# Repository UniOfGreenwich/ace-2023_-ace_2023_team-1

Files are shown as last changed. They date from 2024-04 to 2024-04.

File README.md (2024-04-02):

Review Assignment Due Date (https://classroom.github.com/a/vcAhwuzK)
# Design & Development of a Modular High-Performance Computer (HPC)
## ELEE1119 Advanced Computer Engineering | Academic Year 2023/24
<p align="center">
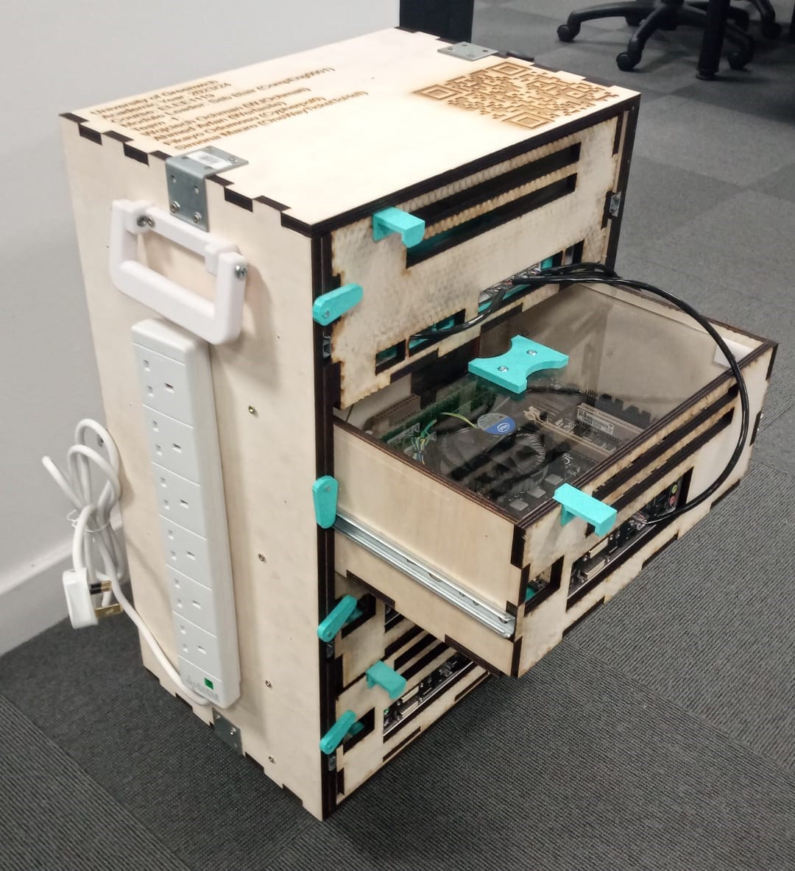
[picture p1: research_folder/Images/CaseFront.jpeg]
Front Case
  
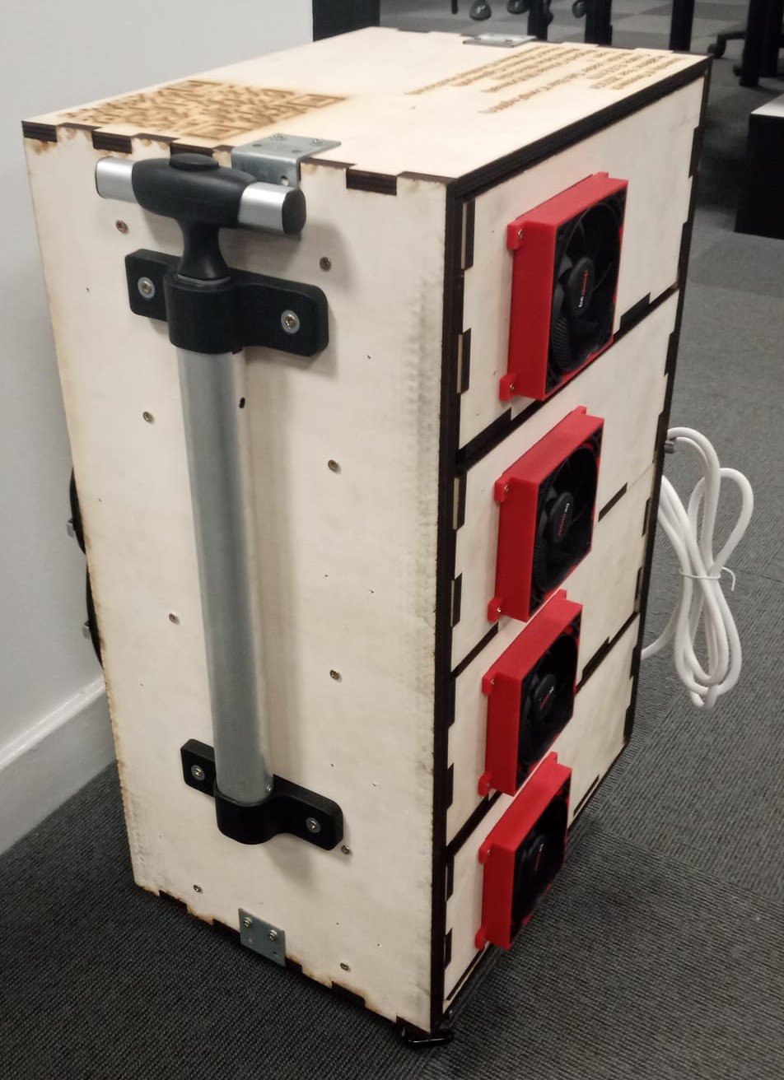
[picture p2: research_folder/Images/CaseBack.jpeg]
Back Case
  
</p>

## Table of Contents
- [Design \& Development of a Modular High-Performance Computer (HPC)](#design--development-of-a-modular-high-performance-computer-hpc)
  - [ELEE1119 Advanced Computer Engineering | Academic Year 2023/24](#elee1119-advanced-computer-engineering--academic-year-202324)
  - [Table of Contents](#table-of-contents)
  - [Video](#video)
  - [Introduction](#introduction)
  - [Setup](#setup)
  - [Design and Manufacturing](#design-and-manufacturing)
    - [Cooling overview](#cooling-overview)
  - [Software Implementation](#software-implementation)
    - [PXE Boot](#pxe-boot)
    - [OpenSSH](#openssh)
    - [Slurm](#slurm)
    - [Testing with R](#testing-with-r)
  - [Recommendations](#recommendations)
  - [Contributors](#contributors)
  - [License](#license)

## Video
<p align="center">
  <a href="https://www.youtube.com/watch?v=2bO4xLcN6Lk" title="Watch the Video">
    Video Report
  </a>
</p>

## Introduction
Welcome to the README file for the Advanced Computer Engineering module at the University of Greenwich, Academic Year 2023/24. This module is lead by Sebastian Blair. This project has been developed by `Team -1`. For full list of contributors consider the [contributors](#contributors) section.

This document provides an overview of the Design and Implementation of the High Performance Computing (HPC) System, including a brief explanation of the steps taken to develop the final products: a prototype, video and documentation demonstrating the collaborative effort and technical approach.

The HPC involves using multiple and interconnected computers in a cluster to perform complex computations. These clusters are nodes managed by schedulers to optimise resource usage. LinuxⓇ is the leading operating system for HPC. It is important to note that although a significant milestone has been reached with the creation of this prototype, there is room for further development and improvements.

## Setup
To carry out this project, the foundational components required are a Raspberry Pi (Model 4B), 3 Motherboards (ASUS CSB), and a 4/5 port switch. The Raspberry Pi acts as the head node, and the motherboards acting as compute nodes.

## Design and Manufacturing
To manufacture a copy of the HPC, an FDM (Fused Deposition Modeling) 3D Printer is necessary with a minimum hotbed size of 300 by 300mm, and a laser cutter with the minimum size of 300 by 600mm. 

PLA (Polylactic Acid) has been used as the filament of choice in this prototype, however ABS or PETG are just as appropriate. The laser cutting has been done using 9mm thick plywood, it is recommended to keep the thickness at 9mm. However, alternative materials such as acrlyic may be used instead of plywood. All CAD, STL, 3VS, and DXF design files can be located in the `hpc_case_design` folder of this repository. [Click Here](/hpc_case_design/design_readme.md) to learn more about the design and manufacturing of this project. 

### Cooling overview
Cooling for this HPC was done through a combination of various cooling methods like row cooling, forced convection and raised floor cooling. Knowing the wattage of the HPC allowed for calculation of the cooling requirements using BTU/br. With the intake of cool air, the exhaust space was calculated.</br> View the link below for more info:

- [Click Here](/hpc_case_design/cooling)

## Software Implementation
The HPC cluster here has been setup with two partitions, mycluster and mycluster2 with each having 2 nodes. The nodes are name node01, node02, node03 and node04. node01(headnode) and node04 are part of partition mycluster whereas node02 and node03 are part of partition mycluster2.

### PXE Boot
PXE (Pre-Boot Execution Environment) is a network protocol that allows a computer to boot and load its OS using resources from a server rather than local storage (USB stick, SSD, Hard Dive, etc.). This is done by leveraging the capabilities of DHCP, TFTP and NFS.
The three main packages used as DHCPD, TFTPD and NFS-Server.
DHCPD is used to create a network. TFTPD is used to create a TFTP Server and NFS is to share the OS image and kernel files. 

[Click here](/research_folder/Software/Implementation/PXE.md) to perform these prerequisite steps and PXE boot as a whole.

1. NETWORK SETUP - DHCP
   
   Firstly, all computers in the HPC setup must be able to communicate with each other. The Compute nodes (ASUS motherboards) are all connected to the head node (Raspberry pi) via LAN and are in network. Here, the DHCP (Dynamic Host Configuration Protocol) is used to allow the devices in the network (the other compute nodes) to be dynamically assigned an IP address. This simplifies the process of configuring IP addresses as it is not necessary to perform static routing and addressing on each device of the HPC. Additionally, DHCP assigns the subnet mask, default gateway, domain name server address and other configurations.
   
   To setup DHCP and get more in depth info, [click here](/research_folder/Software/Implementation/PXE.md#dhcp-server) and go to DHCP setup. 
   
<p align="center">
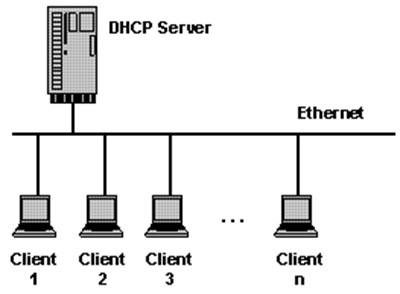
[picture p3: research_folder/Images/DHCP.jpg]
  
</p>

2. SETTING UP TFTP SERVER_
   
   TFTP (Trivial File Transfer Protocol) is a simple, lightweight protocol used to transfer files between devices on a network. It is used to specify the directory which the TFTP server needs to  server to the client. In this case, it is used to serve all the related files required for booting and show the PXE Boot menu, where users can select the operating system to install. Since all related files are stored in the tftpboot directory, this is shared using TFTP.

   To setup TFTP and get more in depth info, [click here](/research_folder/Software/Implementation/PXE.md#configure-tftp-server) and go to TFTP setup.

3. NFS
   
   After selecting the operating system, it is important for users to be able to load the images, kernel files and more. These files need to be accessible over the network. Therefore, NFS (Network File System) is used. This can be done by adding the directory which contains these files as a shared directory across the network. 

   An ISO image of an Ubuntu distribution is firstly installed and mounted. Here, a live installer of Ubuntu 20.04 is installed. It is then copied to a certain directory (ubuntu). This directory now contains all the iso files necessary to install the OS on a machine. This directory needs to be exported over the network and available to compute nodes. Hence it must be configured in the NFS exports file.

   Finally, the PXE Boot menu needs to be configured. The initrd (Initial RAM disk)and vmlinuz (kernel image) files are required to be fetched once user selects operating system. This must be specified in the Boot menu file.

   To setup NFS and get more in depth info, [click here](/research_folder/Software/Implementation/PXE.md#nfs) and go to NFS section. 

Given below is an overview of the entire process
<p align="center">
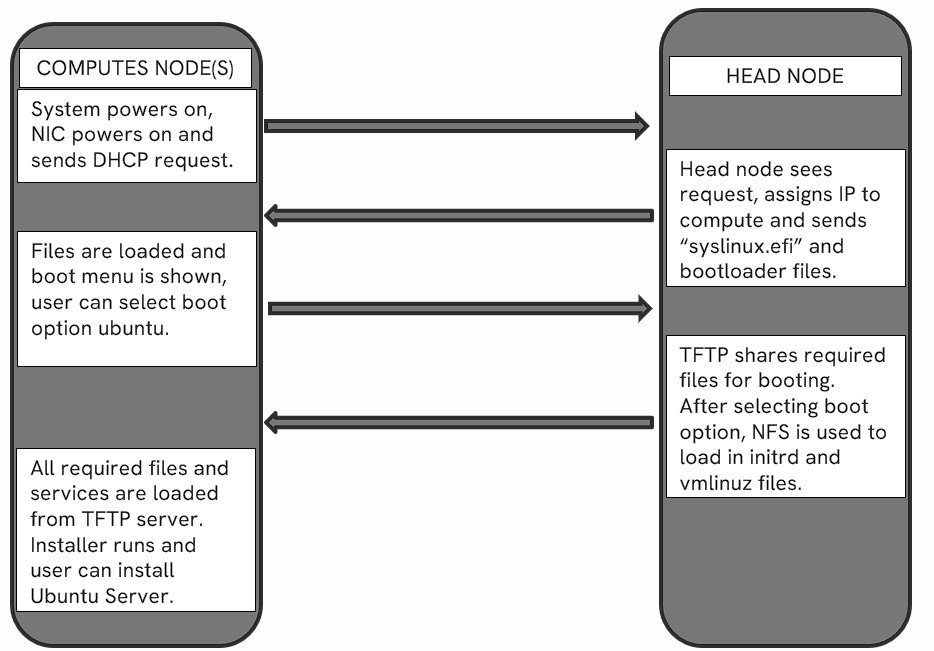
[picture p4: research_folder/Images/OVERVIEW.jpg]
Overview
  
</p>

### OpenSSH
A prerequisite for slurm, to allow secure file transfer and communication between nodes. Allows remote access to compute nodes.</br> For instructions on setting up OpenSSH [Click Here](/research_folder/Software/Implementation/OpenSSH.md#openssh-setup)

### Slurm
Slurm is a highly scalable and flexible workload manager used primarily in HPC environments. Slurm provides mechanisms for inter-task communication and coordination, allowing tasks to share data or synchronize their operations as needed.</br>
SLURM needs to be able to perform its jobs on any node of the cluster. This makes it so that each node should be able to access the same files. Therefore, a shared storage would have to be created. In this project, a 16GB USB drive connected to the head node is exported as a Network File System.

[Click here](/research_folder/Software/Implementation/Slurm.md) to do setup USB as shared storage and setup SLURM between a head node and a compute node. In our setup slurm has been setup for the 4 nodes. Slurmd runs on all nodes whereas node01 runs slurmctld.

### Testing with R

Finally, to test the SLURM setup, an R script is created which generates 10000 random datasets, these datasets are then used to create a density plot jpg. Then the script is run 50 times parallelly on a single partition.  This has been tested and run on the partition mycluster.
Therefore, 50 plots are generated at once, as shown below.

Here are some of the plots:

<p align="center">
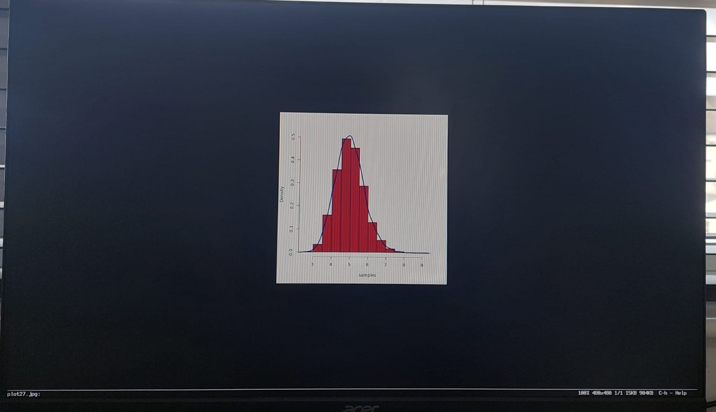
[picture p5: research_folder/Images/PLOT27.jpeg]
Plot 27
  
</p>
<p align="center">
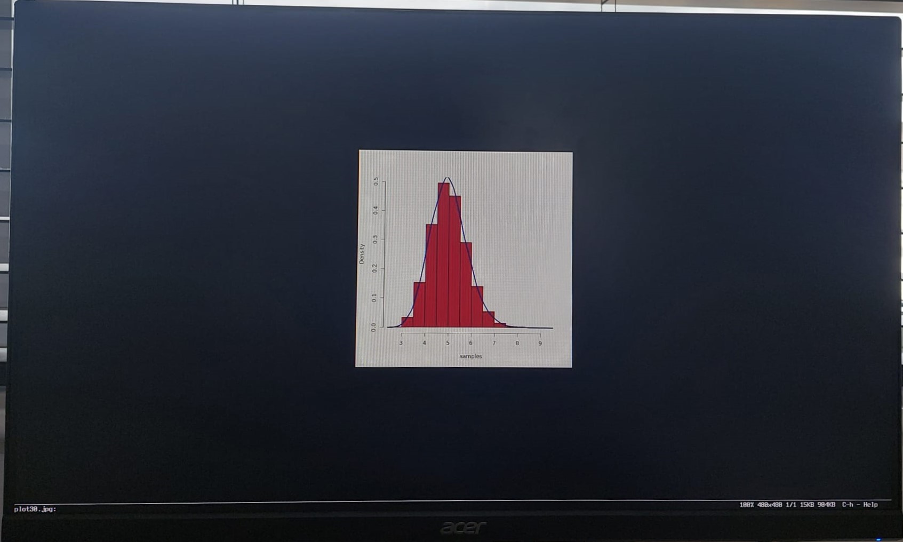
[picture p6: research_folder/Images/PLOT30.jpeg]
Plot 30
  
</p>
<p align="center">
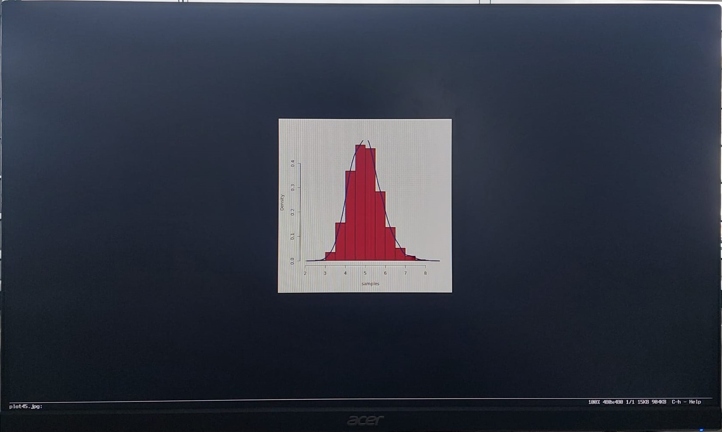
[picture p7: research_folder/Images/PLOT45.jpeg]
Plot 45
  
</p>

[Click here](/research_folder/Software/Implementation/TestRPRogram.md) to view detailed documentation and code.
As a result, SLURM was used to run a job i.e., generating plot from 10000 samples 50 times in parallel. This mimics data processing of large datasets which is a major use case of HPC clusters. 

## Recommendations
Some of the project's next steps include incorporating technologies to improve its capabilities and test its abilities. Integrating SingularityCE can simplify the deployment of complex applications in HPC and scientific computing environments, leveraging containerisation for portability and reproducibility. John the Ripper could enhance security by identifying vulnerabilities in different operating systems. Prometheus and Jaeger will facilitate the monitoring and tracking framework, offering insights into system performance and operational dynamics. Furthermore, these integrations will be relatively easy by taking advantage of Slurm's compatibility with Docker.
Users are encouraged to consult the official documentation linked below for installation guidance on these technologies.

- [SingularityCE Documentation](https://docs.sylabs.io/guides/latest/user-guide/)
- [John the Ripper Documentation](https://github.com/openwall/john/tree/bleeding-jumbo)
- [Prometheus Documentation](https://prometheus.io/docs/prometheus/latest/installation/)
- [Jaeger Documentation](https://www.jaegertracing.io/docs/1.55/getting-started/)

## Contributors
- [@Wertasile](https://github.com/Wertasile)
- [@Cypherpol0](https://github.com/Cypherpol0)
- [@OneWayTicketToHell](https://github.com/OneWayTicketToHell)
- [@WJOchman](https://github.com/WJOchman)
- [@CompEng0001](https://github.com/CompEng0001) - Lecturer

## License
<p xmlns:cc="http://creativecommons.org/ns#" >This work is licensed under <a href="http://creativecommons.org/licenses/by-nc-sa/4.0/?ref=chooser-v1" target="_blank" rel="license noopener noreferrer" style="display:inline-block;">CC BY-NC-SA 4.0</a></p>

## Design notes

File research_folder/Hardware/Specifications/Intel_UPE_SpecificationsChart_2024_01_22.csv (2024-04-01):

UPE | Compare Intel® Products
01/22/2024 12:21:36 PM
 | Intel® Core™ i5-4590 Processor (6M Cache- up to 3.70 GHz)
Essentials
Product Collection | 4th Generation Intel® Core™ i5 Processors
Code Name | Products formerly Haswell
Vertical Segment | Desktop
Processor Number | i5-4590
Lithography | 22 nm
Recommended Customer Price | $202.00
CPU Specifications
Total Cores | 4
Total Threads | 4
Max Turbo Frequency | 3.70 GHz
Intel® Turbo Boost Technology 2.0 Frequency‡ | 3.70 GHz
Processor Base Frequency | 3.30 GHz
Cache | 6 MB Intel® Smart Cache
Bus Speed | 5 GT/s
TDP | 84 W
Supplemental Information
Marketing Status | Discontinued
Launch Date | Q2'14
Expected Discontinuance | 07/14/2017
Servicing Status | End of Servicing Lifetime
End of Servicing Updates Date | Wednesday | June 30 | 2021
Embedded Options Available | No
Datasheet | View now
Memory Specifications
Max Memory Size (dependent on memory type) | 32 GB
Memory Types | DDR3-1333/1600 | DDR3L-1333/1600 @ 1.5V
Max # of Memory Channels | 2
Max Memory Bandwidth | 25.6 GB/s
ECC Memory Supported ‡ | No
GPU Specifications
GPU Name‡ | Intel® HD Graphics 4600
Graphics Base Frequency | 350 MHz
Graphics Max Dynamic Frequency | 1.15 GHz
Graphics Video Max Memory | 2 GB
Graphics Output | eDP/DP/HDMI/VGA
Max Resolution (HDMI)‡ | 4096x2304@24Hz
Max Resolution (DP)‡ | 3840x2160@60Hz
Max Resolution (eDP - Integrated Flat Panel)‡ | 3840x2160@60Hz
Max Resolution (VGA)‡ | 1920x1200@60Hz
DirectX* Support | 11.2/12
OpenGL* Support | 4.3
Intel® Quick Sync Video | Yes
Intel® InTru™ 3D Technology | Yes
Intel® Flexible Display Interface (Intel® FDI) | Yes
Intel® Clear Video HD Technology | Yes
# of Displays Supported ‡ | 3
Device ID | 0x412
Expansion Options
Scalability | 1S Only
PCI Express Revision | Up to 3.0
PCI Express Configurations ‡ | Up to 1x16 | 2x8 | 1x8+2x4
Max # of PCI Express Lanes | 16
Package Specifications
Sockets Supported | FCLGA1150
Max CPU Configuration | 1
Thermal Solution Specification | PCG 2013D
TCASE | 72.72°C
Package Size | 37.5mm x 37.5mm
Advanced Technologies
Intel® Turbo Boost Technology ‡ | 2
Intel® Hyper-Threading Technology ‡ | No
Intel® Transactional Synchronization Extensions | No
Intel® 64 ‡ | Yes
Instruction Set | 64-bit
Instruction Set Extensions | Intel® SSE4.1 | Intel® SSE4.2 | Intel® AVX2
Intel® My WiFi Technology | Yes
Idle States | Yes
Enhanced Intel SpeedStep® Technology | Yes
Thermal Monitoring Technologies | Yes
Intel® Identity Protection Technology ‡ | Yes
Security & Reliability
Intel vPro® Eligibility ‡ | Intel vPro® Platform
Intel® AES New Instructions | Yes
Secure Key | Yes
Intel® OS Guard | Yes
Intel® Trusted Execution Technology ‡ | Yes
Execute Disable Bit ‡ | Yes
Anti-Theft Technology | Yes
Intel® Stable IT Platform Program (SIPP) | Yes
Intel® Virtualization Technology (VT-x) ‡ | Yes
Intel® Virtualization Technology for Directed I/O (VT-d) ‡ | Yes
Intel® VT-x with Extended Page Tables (EPT) ‡ | Yes

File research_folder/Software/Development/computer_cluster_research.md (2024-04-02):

# COMPUTER CLUSTERS

_computer clusters_ are designed to maximise the advantages of parallel computing

In parallel computing tasks are broken down into independent and semi independent operations for simultaneous oepration. this allows for vast increases in computing resources that can be applied to a single tasks allowing for faster execution.

For example, calculation of hours worked, taxes, etc. need to calculated for each employee in a company. Each employees calculations are assigned to separate processor to do all of it simulateneously and faster.

Hardware configuration.

## COMPUTING CLUSTERS - NODE LAYOUT
Computing clusters consist of many specialised nodes

1. HEAD NODE - This is the node into which users must logic to access resources of computer.

2. COMPUTE NODE - Contribute to vast majority of systems computing power. Cannot be accessed by users directly. Instead, Computing jobs must be created on the queue managed by head node.

3. INTERACTIVE NODE - Some computing clusters provide small number of interactive nodes which can be logged into directly. Only intended for small tasks/ short jobs. Alternatively, if interactive nodes are not present, interactive jobs can be launched on compute nodes via the queue.

## COMPUTING CLUSTERS - STORAGE LAYOUT

1. HOME DIRECTORY STORAGE - Users are given small amount of storage for config files, source codew, etc and hsould not be used for large data sets that often form input or output for computational projects.

2. PROJECT STORAGE - large input or output datasets must be stored here.
   
## QUEUES

Queue system may manage several different queues for managing differnet hardware configs

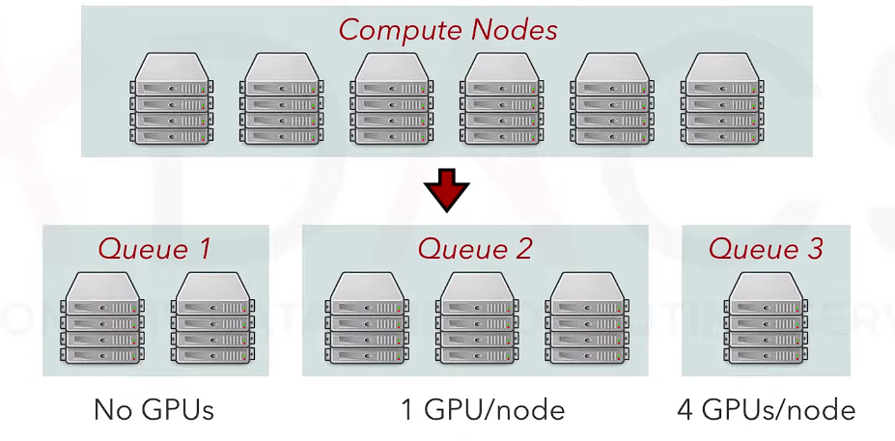
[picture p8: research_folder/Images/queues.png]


It is the responsibility of the user to send the tasks to the correct queue when sent to the queue system.

jobs are submitted to queue system via submission script specify not only the commands to be run by compute nodes but the resources needed as well. the queue system turns the script to a job and specifies job id to identify it.

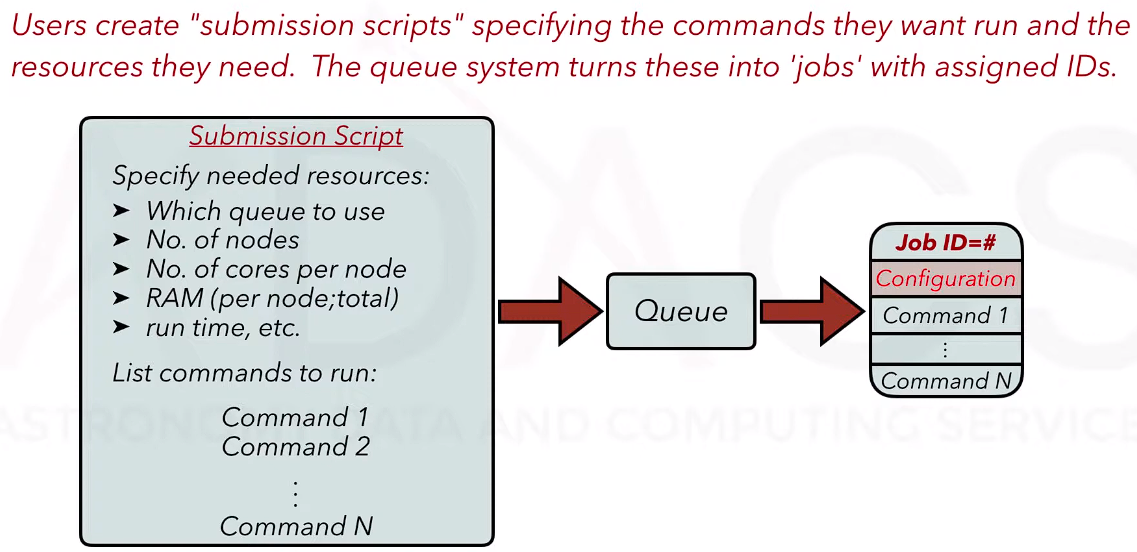
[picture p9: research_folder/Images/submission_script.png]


once jobs are created by queue system they may wait for a bit before starting depending on resources requested and degree to which cluster is being used.

its the job of the queue scheduler to monitor usage patterns of cluster and determine the optimal optimal strategy for starting jobs on computer. It seeks to maximise use of computer and manage equitable access of computer.

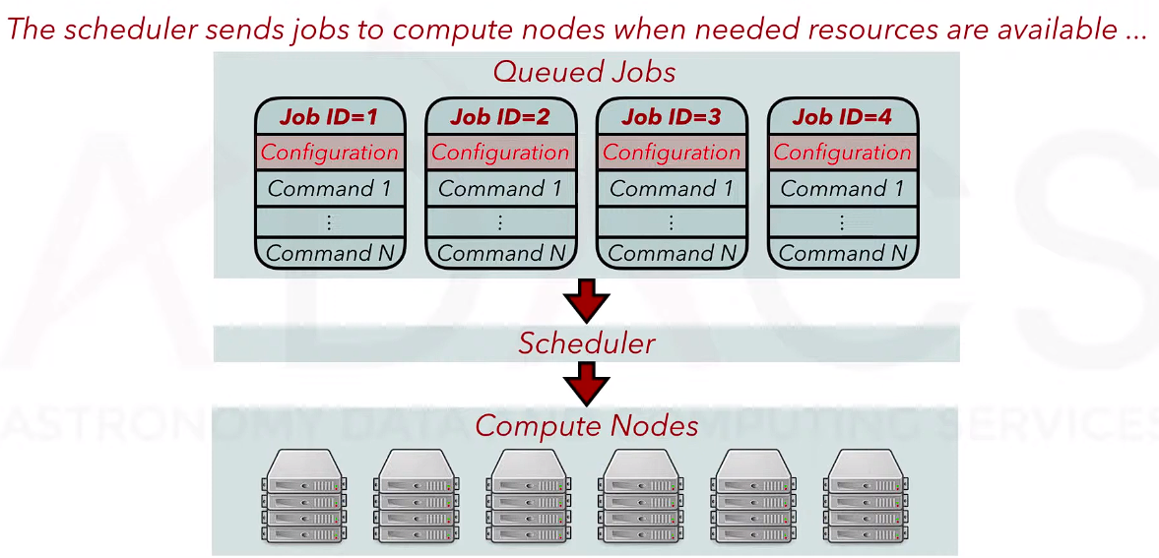
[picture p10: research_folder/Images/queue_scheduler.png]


## SCRIPTS

Operation of computing clusters can be done via a unix command line interface (CLI ) or shell scripts which package sequences of commands allowing for optional arguements. 

Shell script can be created via a text editor like vim.
then system needs to be told the text file is to be considered a executable entity
this is done by setting its permission (read, write and execute) or alternatively,  scripts can be sourced

1. when a shell is executed, a new shell is created or forked and the script is run entirely within the new shell, once complete the forked shell is destroyed and execution return to original shell. As a result, execution occurs in a clean and newly iinitialised environment. 

2. When a script is sourced, it is run within the current shell with its current environment

shell scripts can also receive parameters when executed, and within script these parameters are referenced by a dollar sign followed by a  number $1, $2, $3, ... $n.

## WORKING WITH QUEUES - SUBMISSION SCRIPTS.

submission scripts are shell scripts with additional specialised directives to specify resource requirements, job names, etc. execution privelegesn do not need to be set by chmod. These scripts are sent to the queue with a specialised command which depends on queue system used. Queue management system used here is SLURM - Simple Linux Utility Resource Manager. SLURM submission command is sbastch jobscript.

because there is no way of knowing when or where the job will execute, it is not practical to monitor output of job with the shell we submitted it in. Therefore, standard output produced by job is send to a file. By default, for a jopb with a given name and id the file will be name < name >.o< jobid >

## LOGGING IN COMPUTER CLUSTER

Computing clusters can only be accessed via head nodes, this must be achieved using secure shell (SSH) protocol. external node to compute nodes is not possible.

# SLURM

- preferred way to use a supercomputer is through submitting batch jobs toa  scheduler which governs access to compute nodes

- basic goal of queue system is maximise use of hpc and to do in a fair manner

- ease workload for users and perform complex computation

SLURM is an open source, fault tolerant and highly scalable cluster ,management and job scheduling system for large and small linux clusters.

Developed at Livermore Computing Center, and has grown into a large open source project.

## KEY FUNCTIONS

1. to give users access to rtesources for specified period of time.
   
2. provide a framework for starting, executing and monitoring work on compute nodes.
   
3. to arbitrate contention for resources by managing a queue of pending work.

## ARCHITECTURE

slurm consists of a daemon called slurmd which runs on each compoute node anda  central daemon called alurmctld running on a management node.

info can be queried via several command and can be run in the cluster.

## ENTITIES MANAGED BY SLURM DAEMONS

nodes : computer resources in slurm.

partitions - which group nodes into logical sets, jobs or allocation of resources. can be considered job queues with constraints such as job size limit, job time limit, users permitted to use it, etc.

job steps - set of tasks (maybe parallel) within the job.

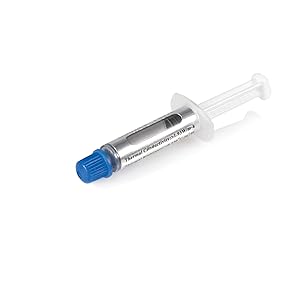
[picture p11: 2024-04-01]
research_folder/Images/thermal_paste_image.jpg

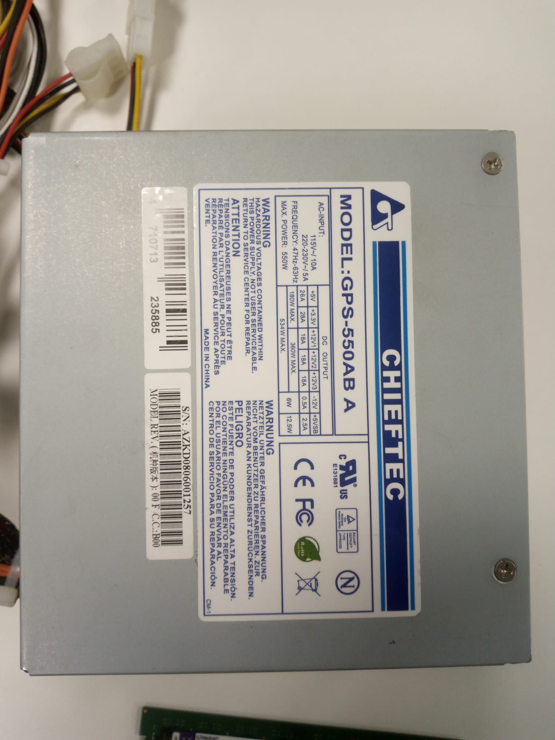
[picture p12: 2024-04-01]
research_folder/Images/PSU550W.jpeg

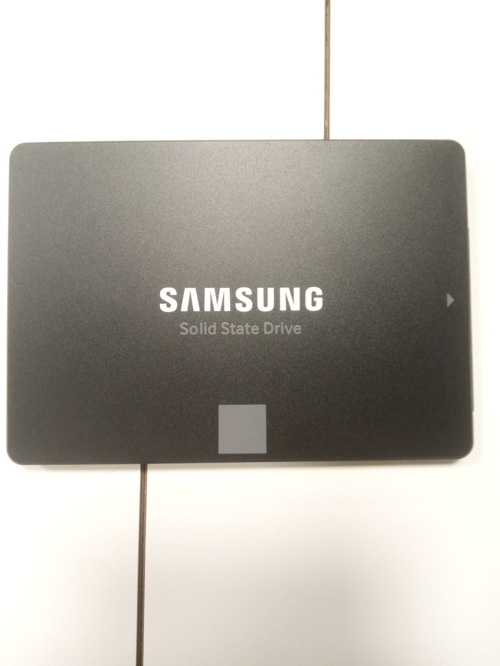
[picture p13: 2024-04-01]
research_folder/Images/SSDfront.jpeg

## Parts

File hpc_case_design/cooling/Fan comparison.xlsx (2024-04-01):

Site | Fan Model | Cp | DT | CFM | Density | W | q (J) | rpm | Dimension | voltage(V) | Connectors
scan.co.uk (http://www.conrad-electronic.co.uk/) | be quiet PURE WINGS 2 | 1.005 | 49 | 33.15 | 1.293 | 42.86295 | 2110.785973 | 1900 | 92x92x25 | 5 | 4-pin
scan.co.uk | Arctic F8 PWM PST Black | 1.005 | 49 | 31 | 1.293 | 40.083 | 1973.887335 | 2000 | 80x80x25 | 12 | 4-pin
scan.co.uk | Noctua NF-A8 | 1.005 | 49 | 32.6 | 1.293 | 42.1518 | 2075.765391 | 2200 | 80x80x25 | 5 | 4-pin
conrad-electronic.co.uk | Sunon PF92251V3-1000U-A99 | 1.005 | 49 | 65 | 1.293 | 84.045 | 4138.796025 | 3900 | 92x92x25 | 6 | 2 Wire leads
conrad-electronic.co.uk | Wallair 20100306 | 1.005 | 49 | 51.57 | 1.293 | 66.68001 | 3283.657092 | 3000 | 92x92x25 | 12 | 2 Wire leads

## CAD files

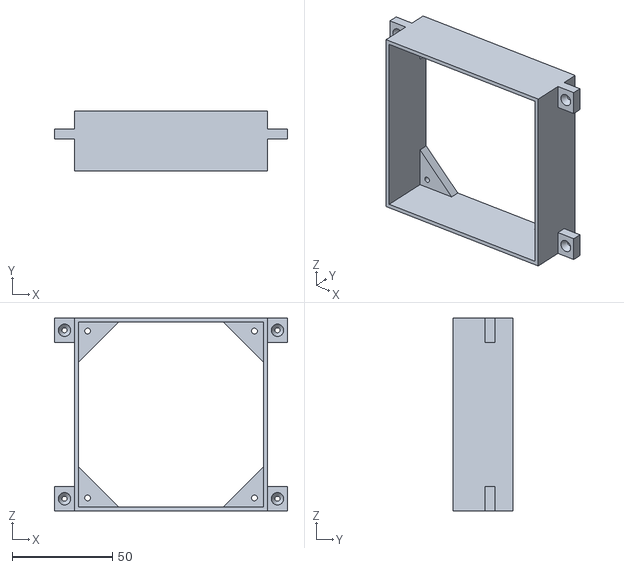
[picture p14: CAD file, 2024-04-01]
hpc_case_design/3d_printing/stl_files/general-shelf/fan_bracket.stl
116.4 x 30.0 x 96.2

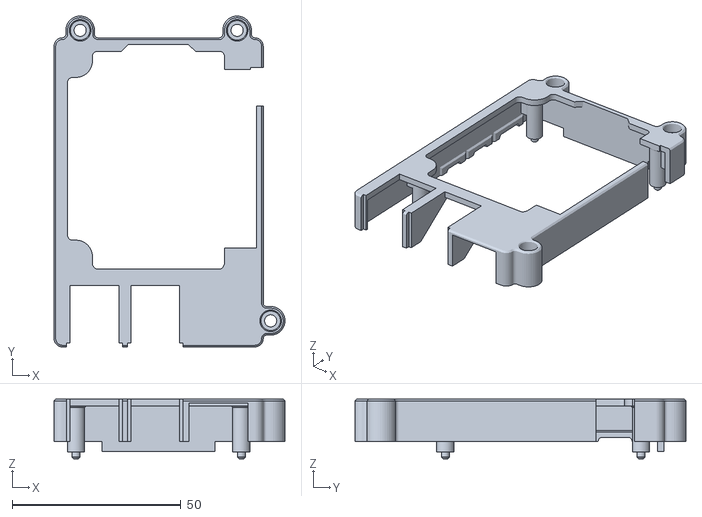
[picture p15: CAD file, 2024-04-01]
hpc_case_design/3d_printing/stl_files/head-shelf/raspi_top.stl
68.4 x 98.0 x 17.7

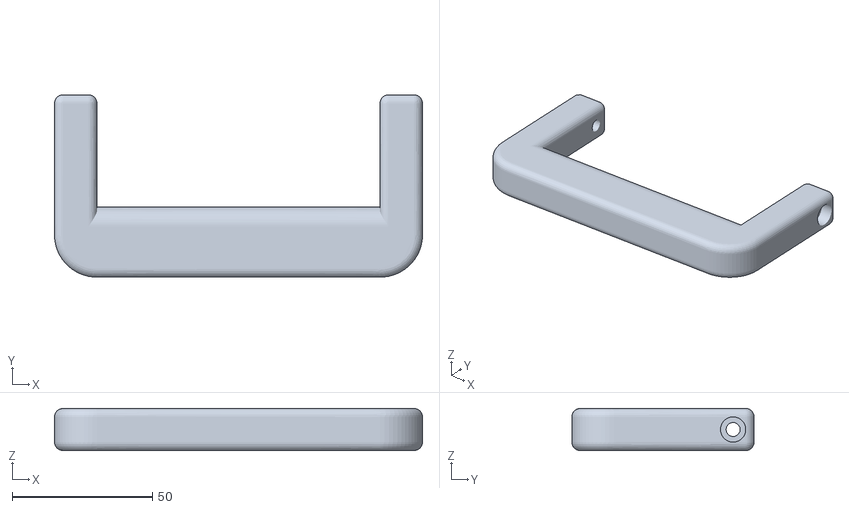
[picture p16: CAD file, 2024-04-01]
hpc_case_design/3d_printing/stl_files/outer-layer/suitcase_handle.stl
131.2 x 65.0 x 15.0

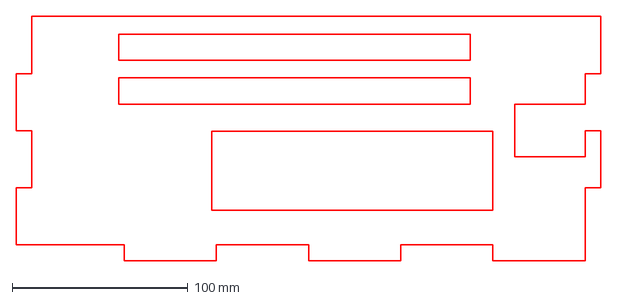
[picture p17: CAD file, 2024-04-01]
hpc_case_design/laser_cutting/dxf_files/inner_shelf/inner_shelf_back.dxf
333.0 x 139.0 mm

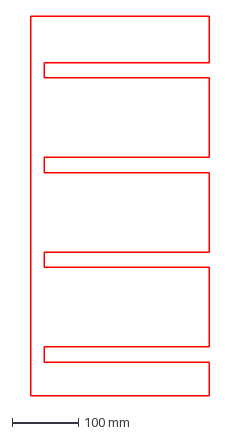
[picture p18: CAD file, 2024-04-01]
hpc_case_design/laser_cutting/dxf_files/outer_shelf/outer_layer_a.dxf
270.0 x 573.0 mm

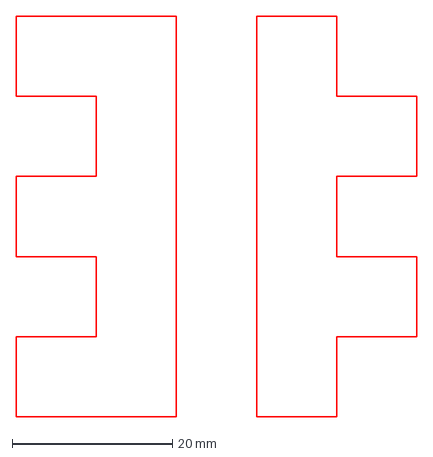
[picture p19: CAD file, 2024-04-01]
hpc_case_design/laser_cutting/dxf_files/testCut.dxf
50.0 x 50.0 mm

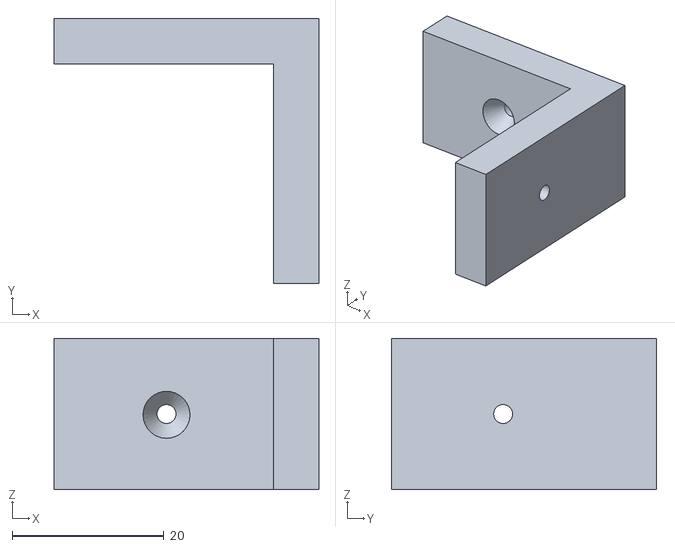
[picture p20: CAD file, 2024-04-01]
hpc_case_design/3d_printing/stl_files/general-shelf/bracket_1.stl
35.0 x 35.0 x 20.0

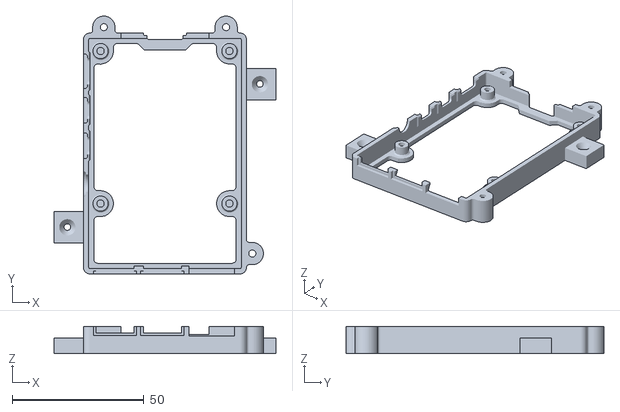
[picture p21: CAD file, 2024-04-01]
hpc_case_design/3d_printing/stl_files/head-shelf/raspi_bottom.stl
84.4 x 98.0 x 10.3

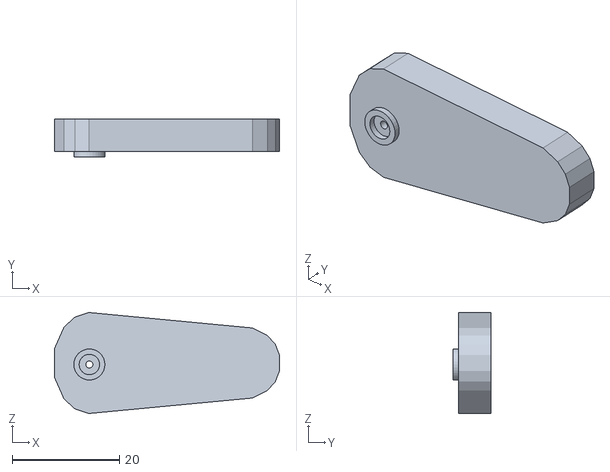
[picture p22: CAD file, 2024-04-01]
hpc_case_design/3d_printing/stl_files/outer-layer/shelf_stopper.stl
41.9 x 7.00 x 18.8

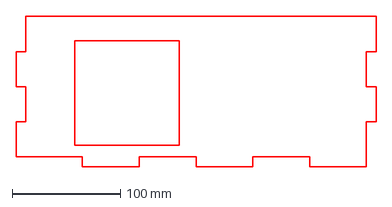
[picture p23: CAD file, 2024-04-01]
hpc_case_design/laser_cutting/dxf_files/inner_shelf/inner_shelf_front.dxf
333.0 x 139.0 mm

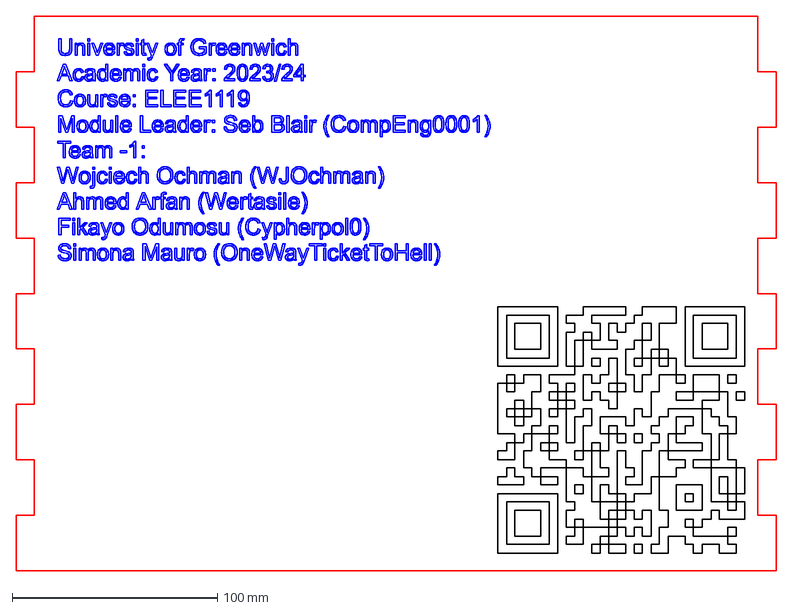
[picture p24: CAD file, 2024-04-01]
hpc_case_design/laser_cutting/dxf_files/outer_shelf/outer_layer_c.dxf
370.0 x 270.0 mm

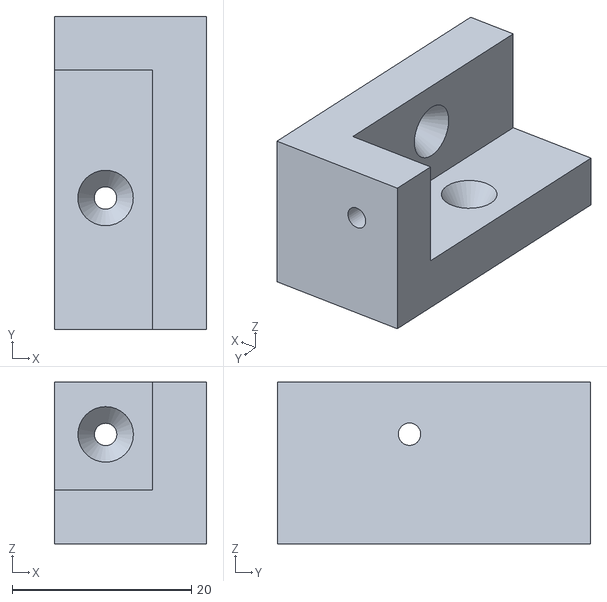
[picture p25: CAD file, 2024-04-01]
hpc_case_design/3d_printing/stl_files/general-shelf/bracket_2a.stl
17.0 x 35.0 x 18.0

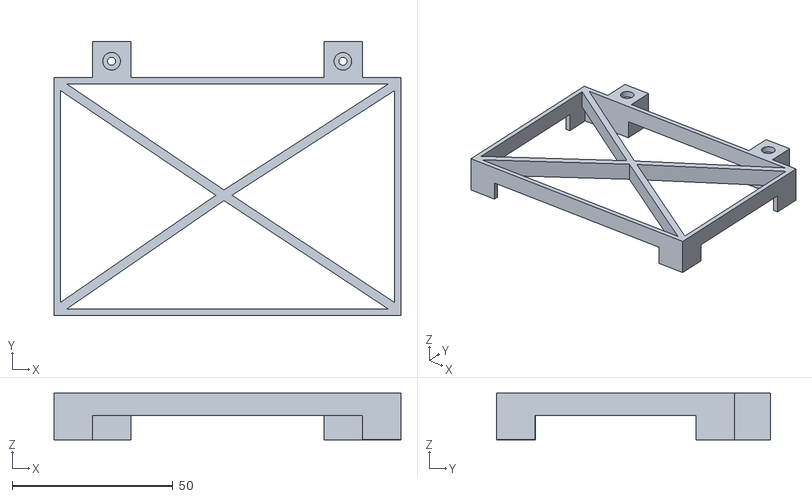
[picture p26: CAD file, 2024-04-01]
hpc_case_design/3d_printing/stl_files/head-shelf/switch_top.stl
108.0 x 85.2 x 14.5

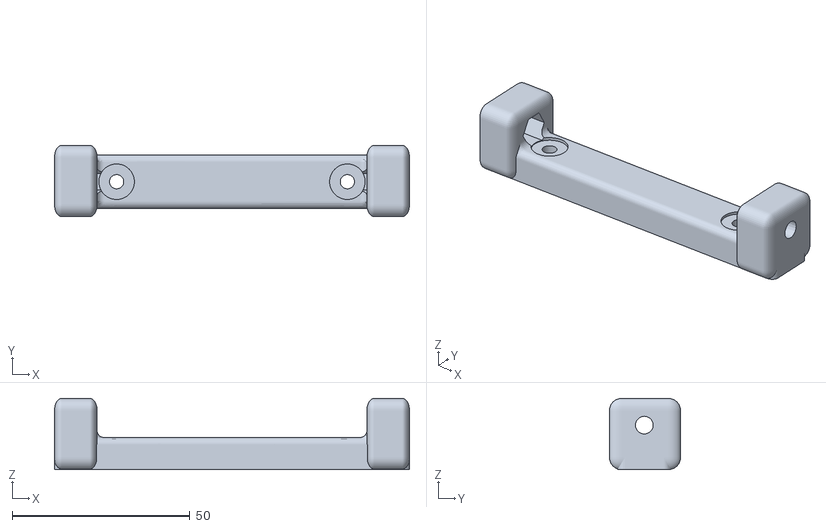
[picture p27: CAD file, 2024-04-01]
hpc_case_design/3d_printing/stl_files/outer-layer/suitcase_base.stl
100.0 x 20.0 x 20.0

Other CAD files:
hpc_case_design/laser_cutting/dxf_files/inner_shelf/inner_shelf_right.dxf
hpc_case_design/laser_cutting/dxf_files/outer_shelf/outer_layer_b.dxf
hpc_case_design/3d_printing/stl_files/general-shelf/shelf_handle.stl
hpc_case_design/3d_printing/stl_files/head-shelf/switch_bottom.stl
hpc_case_design/3d_printing/cad_files/general-shelf/bracket_1.blend
hpc_case_design/3d_printing/cad_files/general-shelf/bracket_2a.blend
hpc_case_design/3d_printing/cad_files/general-shelf/bracket_2b.blend
hpc_case_design/3d_printing/cad_files/general-shelf/bracket_3.blend
hpc_case_design/3d_printing/cad_files/general-shelf/fan_bracket.blend
hpc_case_design/3d_printing/cad_files/general-shelf/shelf_handle.blend
hpc_case_design/3d_printing/cad_files/general-shelf/top_wall_handle.blend
hpc_case_design/3d_printing/cad_files/general-shelf/truss.blend
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

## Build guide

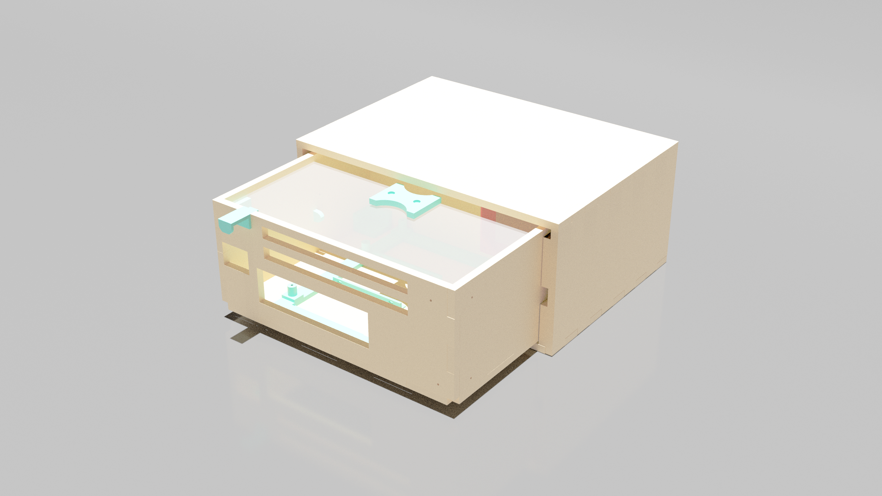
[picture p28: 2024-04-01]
hpc_case_design/3d_printing/cad_files/renders/render_2.png

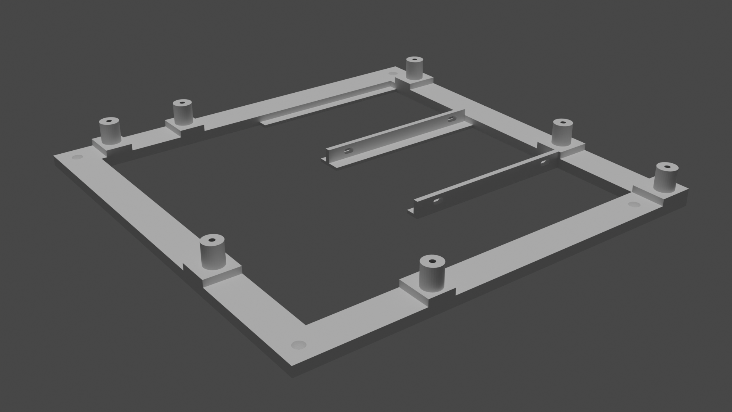
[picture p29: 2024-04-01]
hpc_case_design/3d_printing/cad_files/renders/render_7.png

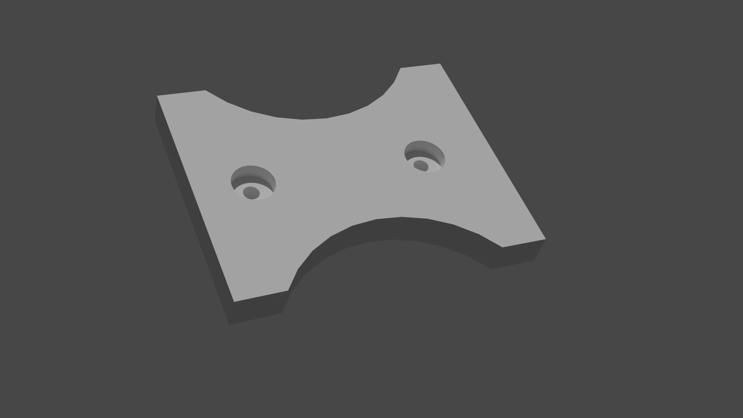
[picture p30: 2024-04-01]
hpc_case_design/3d_printing/cad_files/renders/render_9.png

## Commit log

2024-01-22 Motherboard, Processor, and Thermal Paste Research Commit
    [Intel_UPE_SpecificationsChart_2024_01_22.csv]
2024-02-27 Truss CAD and STL files, Inner-shelf CAD and DXF files
    [Intel_UPE_SpecificationsChart_2024_01_22.csv, inner-shelf_v1.0.blend, inner_shelf_back.dxf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]
2024-03-13 Updated File Structure, Added Latest Shelf Design | 3,746 faces, 5,696 vertices
    [hpc_shelf_design.blend, inner-shelf_v1.0.blend, outer-shelf.blend]
2024-03-13 Added Truss V1 (16 Faces, 16 Vertices) and Truss Hole Test (214 Faces, 274 Vertices)
    [inner-shelf_v1.0.blend, outer-shelf.blend, truss.blend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]
2024-03-13 Added Truss V2 (734 Faces, 912 Vertices)
    [truss.blend]
2024-03-13 Added Truss V3 (903 Faces, 1192 Vertices)
    [truss.blend]
2024-03-13 Added Truss V4 (1067 Faces, 1482 Vertices)
    [truss.blend]
2024-03-13 Added Truss V5 (1290 Faces, 1709 Vertices)
    [truss.blend]
2024-03-13 Added Truss V5 STL and Truss Hole Test STL
    [truss.stl, truss_hole_test.blend, truss_hole_test.stl]
2024-03-13 Added Bracket 1 Design for Inner Shelf (152 Faces, 211 Vertices)
    [bracket_1.blend]
2024-03-13 Added Bracket 2a Design for Inner Shelf (239 Faces, 314 Vertices)
    [bracket_2a.blend]
2024-03-13 Added Bracket 2b Design for Inner Shelf (239 Faces, 314 Vertices)
    [bracket_2b.blend]
2024-03-13 Added Bracket 3 Design for Inner Shelf (356 Faces, 464 Vertices)
    [bracket_2b.blend, bracket_3.blend]
2024-03-13 Added STL Files for Brackets 1, 2a, 2b, 3
    [bracket_1.stl, bracket_2a.stl, bracket_2b.stl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]
2024-03-13 Added Fan Bracket V1 (Faces 78, Vertices 93)
    [fan_bracket.blend]
2024-03-14 Organize files into directories
    [Intel_UPE_SpecificationsChart_2024_01_22.csv]
2024-03-14 Added Fan Bracket STL File and CAD File (Faces 498, Vertices 732)
    [fan_bracket.blend, fan_bracket.stl]
2024-03-16 7 .dxf Files for Inner Shelf, 4 .dxf Files for Outer Shelf
    [inner_shelf_back.dxf, inner_shelf_bottom.dxf, inner_shelf_front.dxf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]
2024-03-23 Added Head Shelf Design (Faces 3822) & General Shelf Design (Faces 4423, Vertices 6790)
    [head_shelf_design.blend, shelf_design.blend]
2024-03-23 Removed hpc_shelf_design, Updated head_shelf_design (Faces 3822)
    [hpc_shelf_design.blend]
2024-03-31 Head Shelf Design (Faces 3,804 | Vertices 5,804)
    [head_shelf_design.blend]
2024-03-31 General Shelf Design (Faces 4,402 | Vertices 6,753)
    [shelf_design.blend]
2024-03-31 Shelf Handle Design (Faces: 45 | Vertices: 56)
    [shelf_handle.blend]
2024-03-31 Top Wall Handle (Faces: 223 | Vertices: 308)
    [top_wall_handle.blend]
2024-03-31 Switch Frame Bottom Piece (Faces: 340 | Vertices: 468)
    [switch_bottom.blend]
2024-03-31 Switch Frame Top Piece (Faces: 308 | Vertices: 384)
    [switch_top.blend]
2024-03-31 Moved 'truss.blend' and 'truss_hole_test.blend' from 'truss' folder to 'general-shelf' folder. Renamed 'inner-shelf' to 'general-shelf'.
    [bracket_1.blend, bracket_2a.blend, bracket_2b.blend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]
2024-03-31 Raspberry Pi Frame Bottom Piece (Faces: 5,386 | Vertices: 2,892)
    [raspi_bottom.blend]
2024-03-31 Raspberry Pi Frame Top Piece (Faces: 5,869 | Vertices: 3,012)
    [raspi_top.blend]
2024-03-31 Shelf Stopper (Faces: 148 | Vertices: 224)
    [shelf_stopper.blend]
2024-03-31 Suitcase Handle and Support (Faces: 7,936 | Vertices: 3,974)
    [handle-support.blend, handle.blend]
2024-03-31 General Shelf STL Files (9 Items)
    [bracket_1.stl, bracket_2a.stl, bracket_2b.stl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]
2024-03-31 Head Shelf STL Files (4 Items)
    [raspi_bottom.stl, raspi_top.stl, switch_bottom.stl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]
2024-03-31 Outer Layer STL Files (3 Items)
    [shelf_stopper.stl, suitcase_base.stl, suitcase_handle.stl]
2024-04-01 Fan comparison, OpenSSH, cooling req
    [Fan comparison.xlsx]
2024-04-01 Removed DXF Handle, Added Head Shelf Back Wall
    [inner_head_shelf_back.dxf]
2024-04-01 Removed Redundant DXF Outer Layer Files, Added Updated DXF Outer Layer Files
    [outer_layer_a.dxf, outer_layer_b.dxf, outer_layer_c.dxf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]
2024-04-01 File structure changed
    [Fan comparison.xlsx, Intel_UPE_SpecificationsChart_2024_01_22.csv]
